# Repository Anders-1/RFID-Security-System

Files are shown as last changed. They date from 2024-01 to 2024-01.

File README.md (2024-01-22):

# RFID-Security-System
An RFID Security System based on the Raspberry Pi Pico (revised from the Zero to Pico).

Version History:

<!-- If you put two spaces after a line it makes a new line but not as big 🤷 -->

V1. RPi Zero  
V2. RPi Pico  
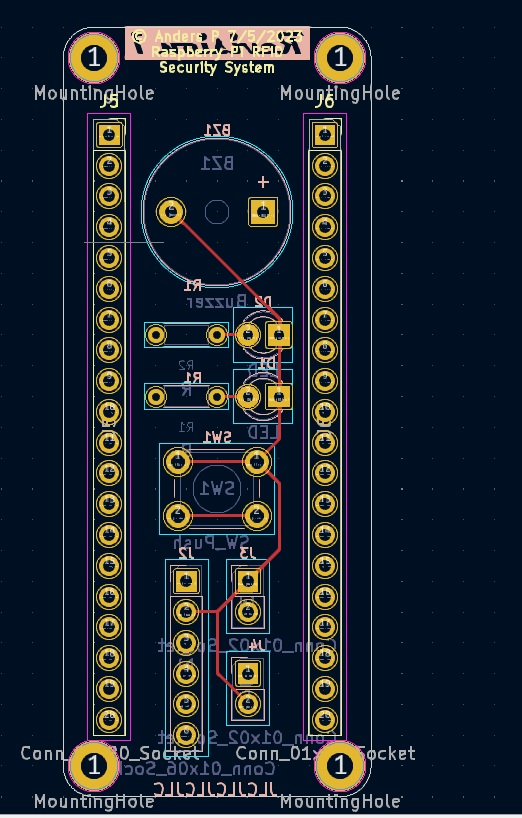
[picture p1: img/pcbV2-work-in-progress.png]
Sneak peak at version 2
  
V3. :shipit: :trollface: :octocat:  

### [CODE](/main.py)

[Tutorial 1](https://littlebirdelectronics.com.au/guides/181/nfc-module-with-raspberry-pi)

[Tutorial 2](https://learn.adafruit.com/adafruit-nfc-rfid-on-raspberry-pi/testing-it-out)

[Tutorial 3](https://core-electronics.com.au/guides/piicodev-rfid-module-guide-for-raspberry-pi/)

[Tutorial 4](http://wiki.sunfounder.cc/index.php?title=PN532_NFC_Module_for_Raspberry_Pi) (with pinout!!!)

[Tutorial 5](https://www.waveshare.com/w/upload/8/83/Nfc-tools_reference_manual.pdf) (reference manual; scroll down)

TODO: 

- [X] Add green light

- [ ] Add startup checker (with beeps and stuff)

- [ ] Document what lights and beeps mean

- [ ] Email when alarm goes off

- [ ] Check todo list in the code too

> [!NOTE]
> This design also works with RPi Zero

Pinout:

| **PN532 NFC RFID Reader** | **Raspberry Pi** |
| --- | --- |
| 5V | 5V |
| GND | GND |
| RX | UART TX |
| TX | UART RX |

| **Breadboard** | **Raspberry Pi** |
| --- | --- |
| Button | GND, GPIO 23 |
| Button 2 (external?) | GND, GPIO 25 |
| Red LED | 220 Ohm resistor, GND |
| 220 Ohm Resistor (for red led) | Red LED, GPIO 17 |
| Green LED | 220 Ohm resistor, GND |
| 220 Ohm Resistor (for green led) | Green LED, GPIO 24 |
| Door Sensor | GND, GPIO 22 |
| Buzzer | GND, GPIO 27 |

Prices:

| Name | Price (totals ignore “other”s) |
| --- | --- |
| [RFID Tag](https://www.adafruit.com/product/4033) | $2.95 |
| [(other) Pi Cobbler](https://www.adafruit.com/product/2029) | $6.95 |
| [(other) RFID Controller](https://www.adafruit.com/product/364) | $39.95 |
| [(other) RFID Controller](https://www.amazon.com/dp/B01I1J17LC) | $8.69 |
| [(other) RFID Controller](https://www.amazon.com/HiLetgo-RFID-Kit-Arduino-Raspberry/dp/B01CSTW0IA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\&linkCode=ll2\&linkId=5c768527322a93c3f1ae3883817b8d14\&qid=1661434446\&s=electronics\&sr=1-1-spons\&psc=1\&spLa=ZW5jcnlwdGVkUXVhbGlmaWVyPUFUWDZGRjdQR01aVzEmZW5jcnlwdGVkSWQ9QTA5OTEzNDNVQjBDOTlMNVlTSEkmZW5jcnlwdGVkQWRJZD1BMDAxMjEzNzNNTEVBRUszQTlRS0cmd2lkZ2V0TmFtZT1zcF9hdGYmYWN0aW9uPWNsaWNrUmVkaXJlY3QmZG9Ob3RMb2dDbGljaz10cnVl) | $5.49 |
| [RFID Controller](https://www.ebay.com/itm/381374529898) | $7.88 |
| [Jumper Wires](https://www.adafruit.com/product/1956) | $3.95 |
| [Breadboard](https://www.adafruit.com/product/4539) | $5.00 |
| [Buzzer](https://www.adafruit.com/product/160) | $1.50 |
| [Magnetic Door Switch](https://www.adafruit.com/product/375) | $3.95 |
| [(other) Pi 4 Model B](https://www.pishop.us/product/raspberry-pi-4-model-b-2gb/?src=raspberrypi) | $45.00 |
| [(other) Resistor Pack](https://www.amazon.com/Elegoo-Values-Resistor-Assortment-Ohm-1M/dp/B072BL2VX1) | $11.99 |
| [(other) Resistors + Others Pack](https://www.amazon.com/Smraza-Breadboard-Resistors-Mega2560-Raspberry/dp/B01HRR7EBG) | $12.69 |
| **Total** | **$25.23** |
| _other_| |
| **Grand Total** | **$25.23** |

Getting the pack saves $8.45

I could get the pack and also get Jumper Wires for $3.95, I could get to tinkering earlier.

I could get the pack and get all the other products, $10.45 more expensive than just getting the pack.

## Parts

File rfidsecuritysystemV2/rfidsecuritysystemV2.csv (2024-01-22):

Source: | C:\Users\ahpye\Desktop\rfidsecuritysystem\rfidsecuritysystem.kicad_sch
Date: | 6/19/2023 9:58:35 AM
Tool: | Eeschema 7.0.5
Generator: | C:\Program Files\KiCad\7.0\bin\scripting\plugins/bom_csv_grouped_by_value_with_fp.py
Component Count: | 14
Ref | Qnty | Value | Cmp name | Footprint | Description | Vendor | DNP
BZ1 | 1 | Buzzer | Buzzer | Buzzer_Beeper:Buzzer_12x9.5RM7.6 | Buzzer, polarized
D1, D2 | 2 | LED | LED | LED_THT:LED_D3.0mm | Light emitting diode
H1, H2, H3, H4 | 4 | MountingHole | MountingHole | MountingHole:MountingHole_2.2mm_M2_DIN965_Pad | Mounting Hole without connection
J1 | 1 | Conn_02x20_Odd_Even | Conn_02x20_Odd_Even | Connector_PinHeader_2.54mm:PinHeader_2x20_P2.54mm_Vertical | Generic connector, double row, 02x20, odd/even pin numbering scheme (row 1 odd numbers, row 2 even numbers), script generated (kicad-library-utils/schlib/autogen/connector/)
J2 | 1 | Conn_01x06_Socket | Conn_01x06_Socket | Connector_PinSocket_2.54mm:PinSocket_1x06_P2.54mm_Vertical | Generic connector, single row, 01x06, script generated
J3 | 1 | Conn_01x02_Socket | Conn_01x02_Socket | Connector_PinSocket_2.54mm:PinSocket_1x02_P2.54mm_Vertical | Generic connector, single row, 01x02, script generated
R1, R2 | 2 | R | R | Resistor_THT:R_Axial_DIN0204_L3.6mm_D1.6mm_P5.08mm_Horizontal | Resistor
SW1, SW2 | 2 | SW_Push | SW_Push | Button_Switch_THT:SW_PUSH_6mm | Push button switch, generic, two pins

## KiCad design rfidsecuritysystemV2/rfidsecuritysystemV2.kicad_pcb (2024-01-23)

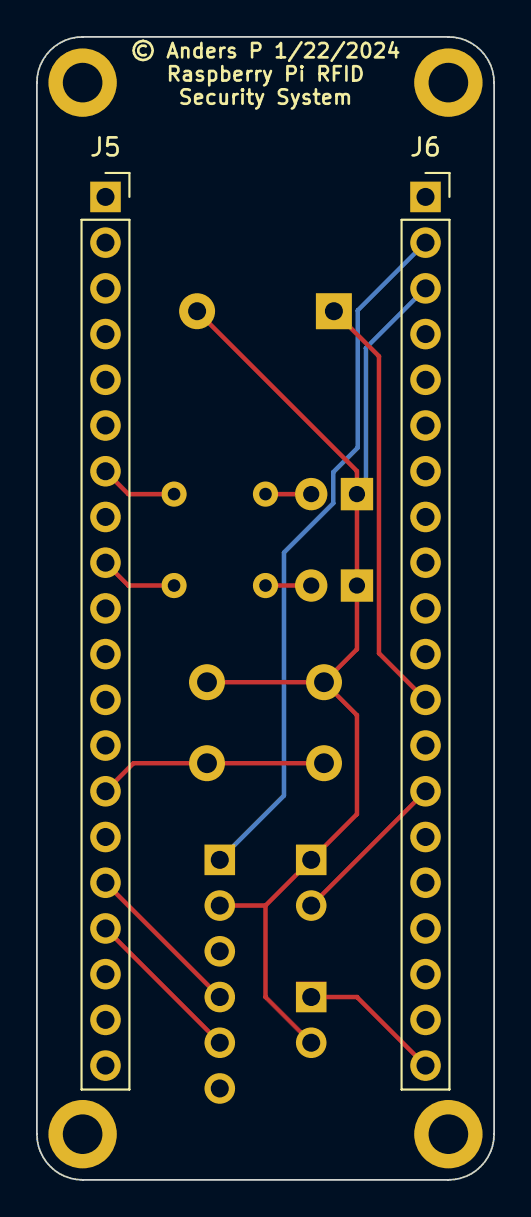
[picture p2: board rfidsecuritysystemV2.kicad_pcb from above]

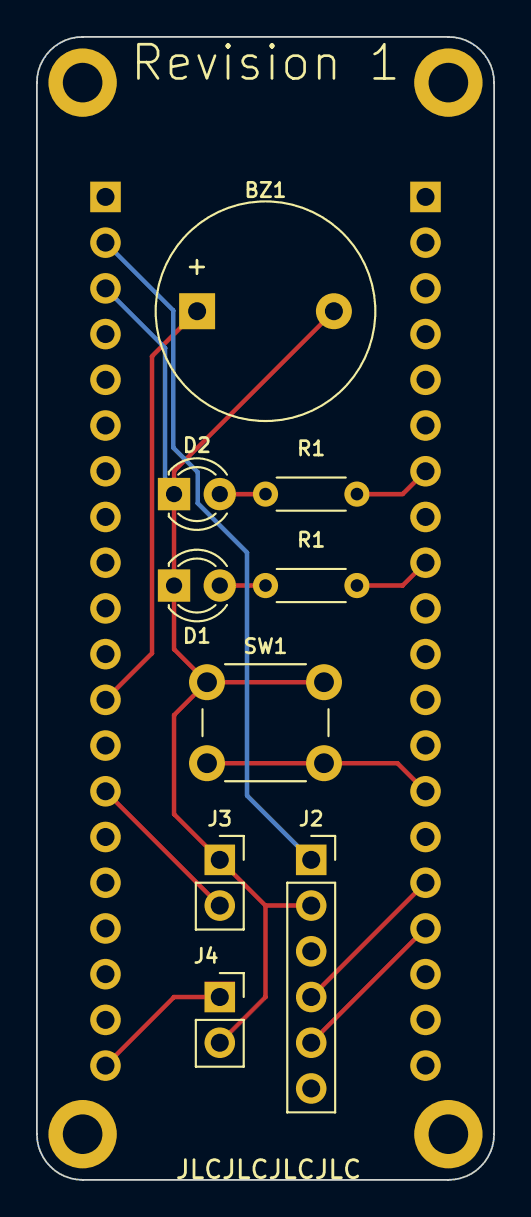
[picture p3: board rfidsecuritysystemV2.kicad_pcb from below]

Board: 2 copper layers, 25.4 x 63.5 mm, 15 parts (9 on the bottom side), 12 nets.

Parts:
BZ1: Buzzer; Buzzer_12x9.5RM7.6
D1, D2: LED; LED_D3.0mm
H1, H2, H3, H4: MountingHole; MountingHole_2.2mm_M2_DIN965_Pad
J2: Conn_01x06_Socket; PinSocket_1x06_P2.54mm_Vertical
J3, J4: Conn_01x02_Socket; PinSocket_1x02_P2.54mm_Vertical
J5, J6: Conn_01x20_Socket; PinSocket_1x20_P2.54mm_Vertical
R1, R2: R; R_Axial_DIN0204_L3.6mm_D1.6mm_P5.08mm_Horizontal
SW1: SW_Push; SW_PUSH_6mm

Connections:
+5V: J2.1, J6.2
/GPIO 5: J5.7, R2.2
/GPIO 6: J5.9, R1.2
/GPIO 10: J5.14, SW1.2
/GPIO 16: J4.1, J6.20
/GPIO 21: J3.2, J6.14
/GPIO 22: BZ1.1 (-), J6.12
/UART RX: J2.5, J5.17
/UART TX: J2.4, J5.16
GND: BZ1.2 (+), D1.1 (K), D2.1 (K), J2.2, J3.1, J4.2, J6.3, SW1.1
unnamed: D1.2 (A), R1.1
unnamed: D2.2 (A), R2.1

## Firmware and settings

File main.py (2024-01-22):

# INSTALLING:
#
# First, use the Adafruit guide to install drivers or whatever (might not be needed, but install
# the drivers anyway just to be sure).
# https://learn.adafruit.com/adafruit-nfc-rfid-on-raspberry-pi
#
# I don't think this site installs anything, it is just example code, but if the reader isn't
# working, try following the steps in this link (after the Adafruit link of course).
# https://www.raspberrypi.com/news/read-rfid-and-nfc-tokens-with-raspberry-pi-hackspace-37/
#
# NOTE TO SELF/COMBAK: Disable alarm after long period of time (like if the door just
# randomly opens when no one is home [not sarcasm]). Also, add Cron Job to run program
# in the morning and close it at bedtime (so it isn't running at night, of course, you could
# always have it run all the time if you want). Also, check the comment/combak on line 125
# and 218. And also check todolist on google doc.

from gpiozero import LED, Button, Buzzer
import time
import datetime
from signal import pause
import threading


def info(text, severe=False):
    current_time = str(datetime.datetime.now())
    if severe:
        print("****")
        print("[IMPORTANT " + current_time + "]: " + text)
        print("****")
    else:
        print("[INFO " + current_time + "]: " + text)

# ----
import RPi.GPIO as GPIO
GPIO.setwarnings(False)

import pn532.pn532 as nfc
from pn532 import *

pn532 = PN532_UART(debug=False, reset=20)

ic, ver, rev, support = pn532.get_firmware_version()
info('Found PN532 with firmware version: {0}.{1}'.format(ver, rev), severe=True)

# Configure PN532 to communicate with NTAG215 cards
pn532.SAM_configuration()
# ----

# Variables
led1 = LED(17)
led2 = LED(24)
buzzer = Buzzer(27)
door_sensor = Button(22, pull_up=None, active_state=True)
button = Button(23)

MASTER_KEY = ['0x4', '0x3a', '0xf3', '0x38', '0xc0', '0x6d', '0x80']
GUEST_KEY = ['0x62', '0xdd', '0x6d', '0x22']

GUEST_COUNTDOWN_TIME = 20
guest_countdown = -1
safely_opened = False

start_time = 0

def blink(wait):
    led1.on()
    time.sleep(wait)
    led1.off()

def blink_green(wait):
    led2.on()
    time.sleep(wait)
    led2.off()

def beep(wait):
    buzzer.on()
    time.sleep(wait)
    buzzer.off()

def blinkandbeep(wait):
    led1.on()
    buzzer.on()
    time.sleep(wait)
    led1.off()
    buzzer.off()
    time.sleep(wait)

def blinkandbeep_green(wait):
    led2.on()
    buzzer.on()
    time.sleep(wait)
    led2.off()
    buzzer.off()
    time.sleep(wait)

def alarm(repeat):
    for _ in range(repeat):
        blinkandbeep(0.1)

def alarm_green(repeat):
    for _ in range(repeat):
        blinkandbeep_green(0.1)

def guest_countdown_handler(action = "DECREMENT"):
    global GUEST_COUNTDOWN_TIME
    global guest_countdown
    global start_time
    if action == "DECREMENT":
        start_time = time.time()
        while guest_countdown > 0:
            current_time = time.time()
            difference = current_time - start_time
            info("Guest countdown at: " + str(difference))
            if (difference % 1 > 0.9):
                blink_green(0.5)
            if difference > GUEST_COUNTDOWN_TIME:
                guest_countdown = 0
                info("Guest countdown complete")
                return
            else:
                time.sleep(0.1)
        return
    elif action == "START":
        if guest_countdown > 0:
#             COMBAK: Uncomment if you want to allow people to reset guest time
#             while the countdown is going on.

#             start_time = time.time()
            return
        guest_countdown = GUEST_COUNTDOWN_TIME
        t1 = threading.Thread(target = guest_countdown_handler, args=("DECREMENT",))
        t1.start()
#         t1.join()
        return
    elif action == "RESET":
        guest_countdown = -1
        return

def door_handler(key=None):
    global safely_opened
    global guest_countdown

    if safely_opened:
        return

    info("Door opened, getting key")
    key = get_key(3, 0.5)
    if key in [None, "NO KEY"] or guest_countdown == 0:
         if not guest_countdown > 0:
            for _ in range(10):
                if get_key(1, 0.1) == "MASTER":
                    guest_countdown_handler("RESET")
                    safely_opened = True
                    return
                else:
                    info("Alarm set off!", severe=True)
                    alarm(1)
    elif key == "MASTER":
        info("Master key opened door")
        guest_countdown_handler("RESET")
        safely_opened = True
        led2.on()
    elif key == "GUEST":
        guest_countdown_handler("START")

def get_key(attempts = 5, wait = 0.5):
    global MASTER_KEY
    global GUEST_KEY
    for _ in range(attempts):
        key = pn532.read_passive_target(timeout=wait)
        if key is not None:
            key = [hex(i) for i in key]
            if key == MASTER_KEY:
                return "MASTER"
                door_handler("MASTER")
            elif key == GUEST_KEY:
                return "GUEST"
            else:
                info("UNKNOWN KEY IS: " + str(key), severe=True)
                return "NO KEY"
        time.sleep(wait)
    return "NO KEY"

def door_close_handler():
    global safely_opened
    info("Checking if door is closed")

    key = get_key(3, 0.5)

    if door_sensor.value == 0:
        safely_opened = False
        led2.off()
        info("Door is closed")
        info("The key when closing is: " + key)
        if key not in [None, "NO KEY"]:
            guest_countdown_handler("RESET")
            info("Guest_Countdown after reset is: " + str(guest_countdown))

def button_handler():
    key = get_key(2, 0.1)
    info("Button pressed. Key is: " + key)
    if key == "MASTER":
        blink_green(0.5)
    elif key == "GUEST":
        blink_green(0.5)
        time.sleep(0.5)
        blink_green(0.5)
    else:
        blink(0.5)

def button_new_thread():
    t2 = threading.Thread(target = button_handler)
    t2.start()

door_sensor.when_pressed = door_handler
door_sensor.when_released = door_close_handler

# COMBAK: Comment this out if people pressing the button is causing problems.
button.when_pressed = button_new_thread

pause()

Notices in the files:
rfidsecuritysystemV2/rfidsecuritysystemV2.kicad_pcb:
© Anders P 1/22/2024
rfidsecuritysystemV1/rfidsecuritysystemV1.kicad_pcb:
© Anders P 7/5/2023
